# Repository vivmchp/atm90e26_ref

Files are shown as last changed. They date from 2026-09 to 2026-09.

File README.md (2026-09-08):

# ATM90E26A Evaluation Board

KiCad 10.0 design for a single-phase energy metering evaluation board based on the Microchip ATM90E26A IC.

| Front | Back |
|:-----:|:----:|
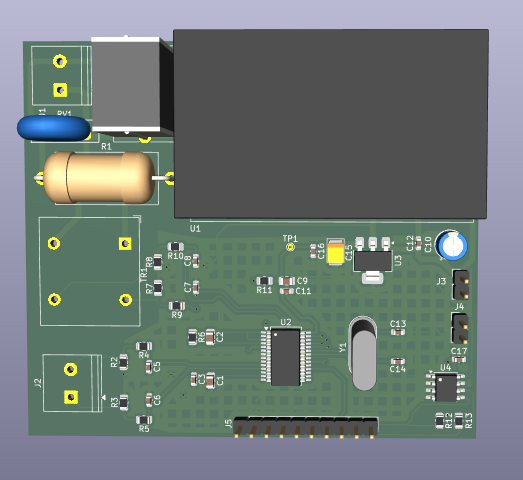
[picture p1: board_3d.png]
Board 3D Front
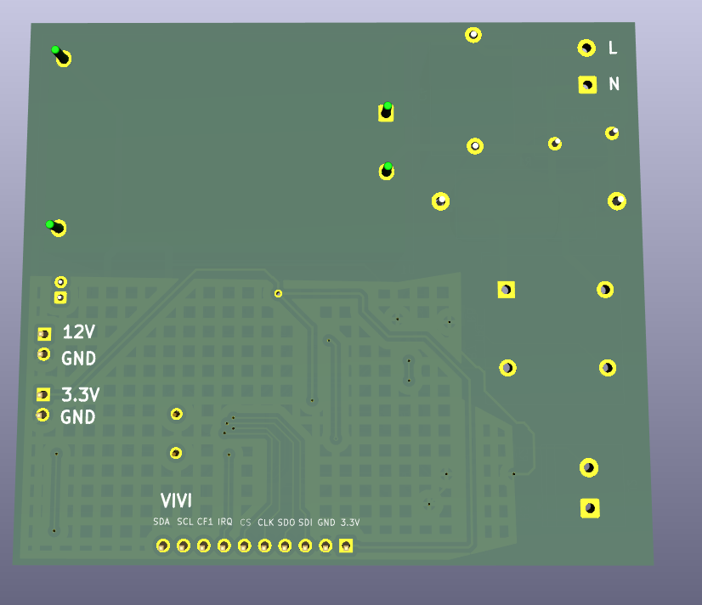
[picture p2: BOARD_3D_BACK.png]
Board 3D Back
|  |  |

## Features

- **ATM90E26A** high-precision energy metering IC (SSOP-28)
- **HLK-10M12** AC/DC power module (100-240VAC input, 12VDC/10W output)
- **ZMPT101K** voltage transformer (1000:1000) for isolated AC voltage sensing
- **MIC5209-3.3YS-TR** LDO for 3.3V power supply
- **24C02C** I2C EEPROM for calibration data storage
- **10D561** varistor for surge protection
- 10-pin header for MCU interface (SPI + I2C)
- Single-phase two-wire or three-wire configuration support

## Block Diagram

Block Diagram

## Connectors

### AC Input (J1)
| Pin | Signal | Description |
|-----|---|---|
| 1 | LINE | AC Live (100-240VAC) |
| 2 | NEUT | AC Neutral |

### Current Input (J2)
| Pin | Signal | Description |
|-----|---|---|
| 1 | I1P | Current channel positive |
| 2 | I1N | Current channel negative |

### MCU Interface (J5)
| Pin | Signal | Description |
|-----|---|---|
| 1 | +3.3V | 3.3V power output |
| 2 | GND | Ground |
| 3 | ATM_SDI | SPI data in (MOSI to ATM90E26) |
| 4 | ATM_SDO | SPI data out (MISO from ATM90E26) |
| 5 | ATM_CLK | SPI clock |
| 6 | ATM_CS | Chip select (active low) |
| 7 | ATM_IRQ | Interrupt output |
| 8 | ATM_CF1 | Energy pulse output |
| 9 | SCL | I2C clock (1K pull-up) |
| 10 | SDA | I2C data (1K pull-up) |

## PCB Specifications

| Parameter | Value |
|---|---|
| Board size | 80mm × 70mm |
| Layers | 2 (Top + Bottom copper) |
| Thickness | 1.6mm |
| Default track | 0.2mm |
| Default via | 0.6mm / 0.3mm drill |
| HV track | 1.0mm |
| HV clearance | 1.0mm |

## Bill of Materials

| Ref | Part | Value | Package |
|-----|---|---|---|
| U1 | HLK-10M12 | 12V/10W | Module |
| U2 | ATM90E26-YU | - | SSOP-28 |
| U3 | MIC5209-3.3YS-TR | 3.3V | SOT-223 |
| U4 | 24C02C | 2Kbit | SOIC-8 |
| TR1 | ZMPT101K | 1000:1000 | Through-hole |
| Y1 | Crystal | 8.192MHz | HC49-U |
| RV1 | Varistor | 10D561 | Disc |
| R1 | Resistor | 200K/3W | Axial |
| C13, C14 | Capacitor | 12pF | 0603 |

## Manufacturing Files

Gerber files for PCB fabrication are in `ATM90E26_EVAL/output/`:

| File | Description |
|---|---|
| *-F_Cu.gbr | Front copper layer |
| *-B_Cu.gbr | Back copper layer |
| *-F_Mask.gbr | Front solder mask |
| *-B_Mask.gbr | Back solder mask |
| *-F_Paste.gbr | Front solder paste |
| *-B_Paste.gbr | Back solder paste |
| *-F_Silkscreen.gbr | Front silkscreen |
| *-B_Silkscreen.gbr | Back silkscreen |
| *-Edge_Cuts.gbr | Board outline |
| *-PTH.drl | Plated through holes |
| *-NPTH.drl | Non-plated holes |

## Requirements

- KiCad 10.0 or later

## License

Reference design for evaluation purposes.

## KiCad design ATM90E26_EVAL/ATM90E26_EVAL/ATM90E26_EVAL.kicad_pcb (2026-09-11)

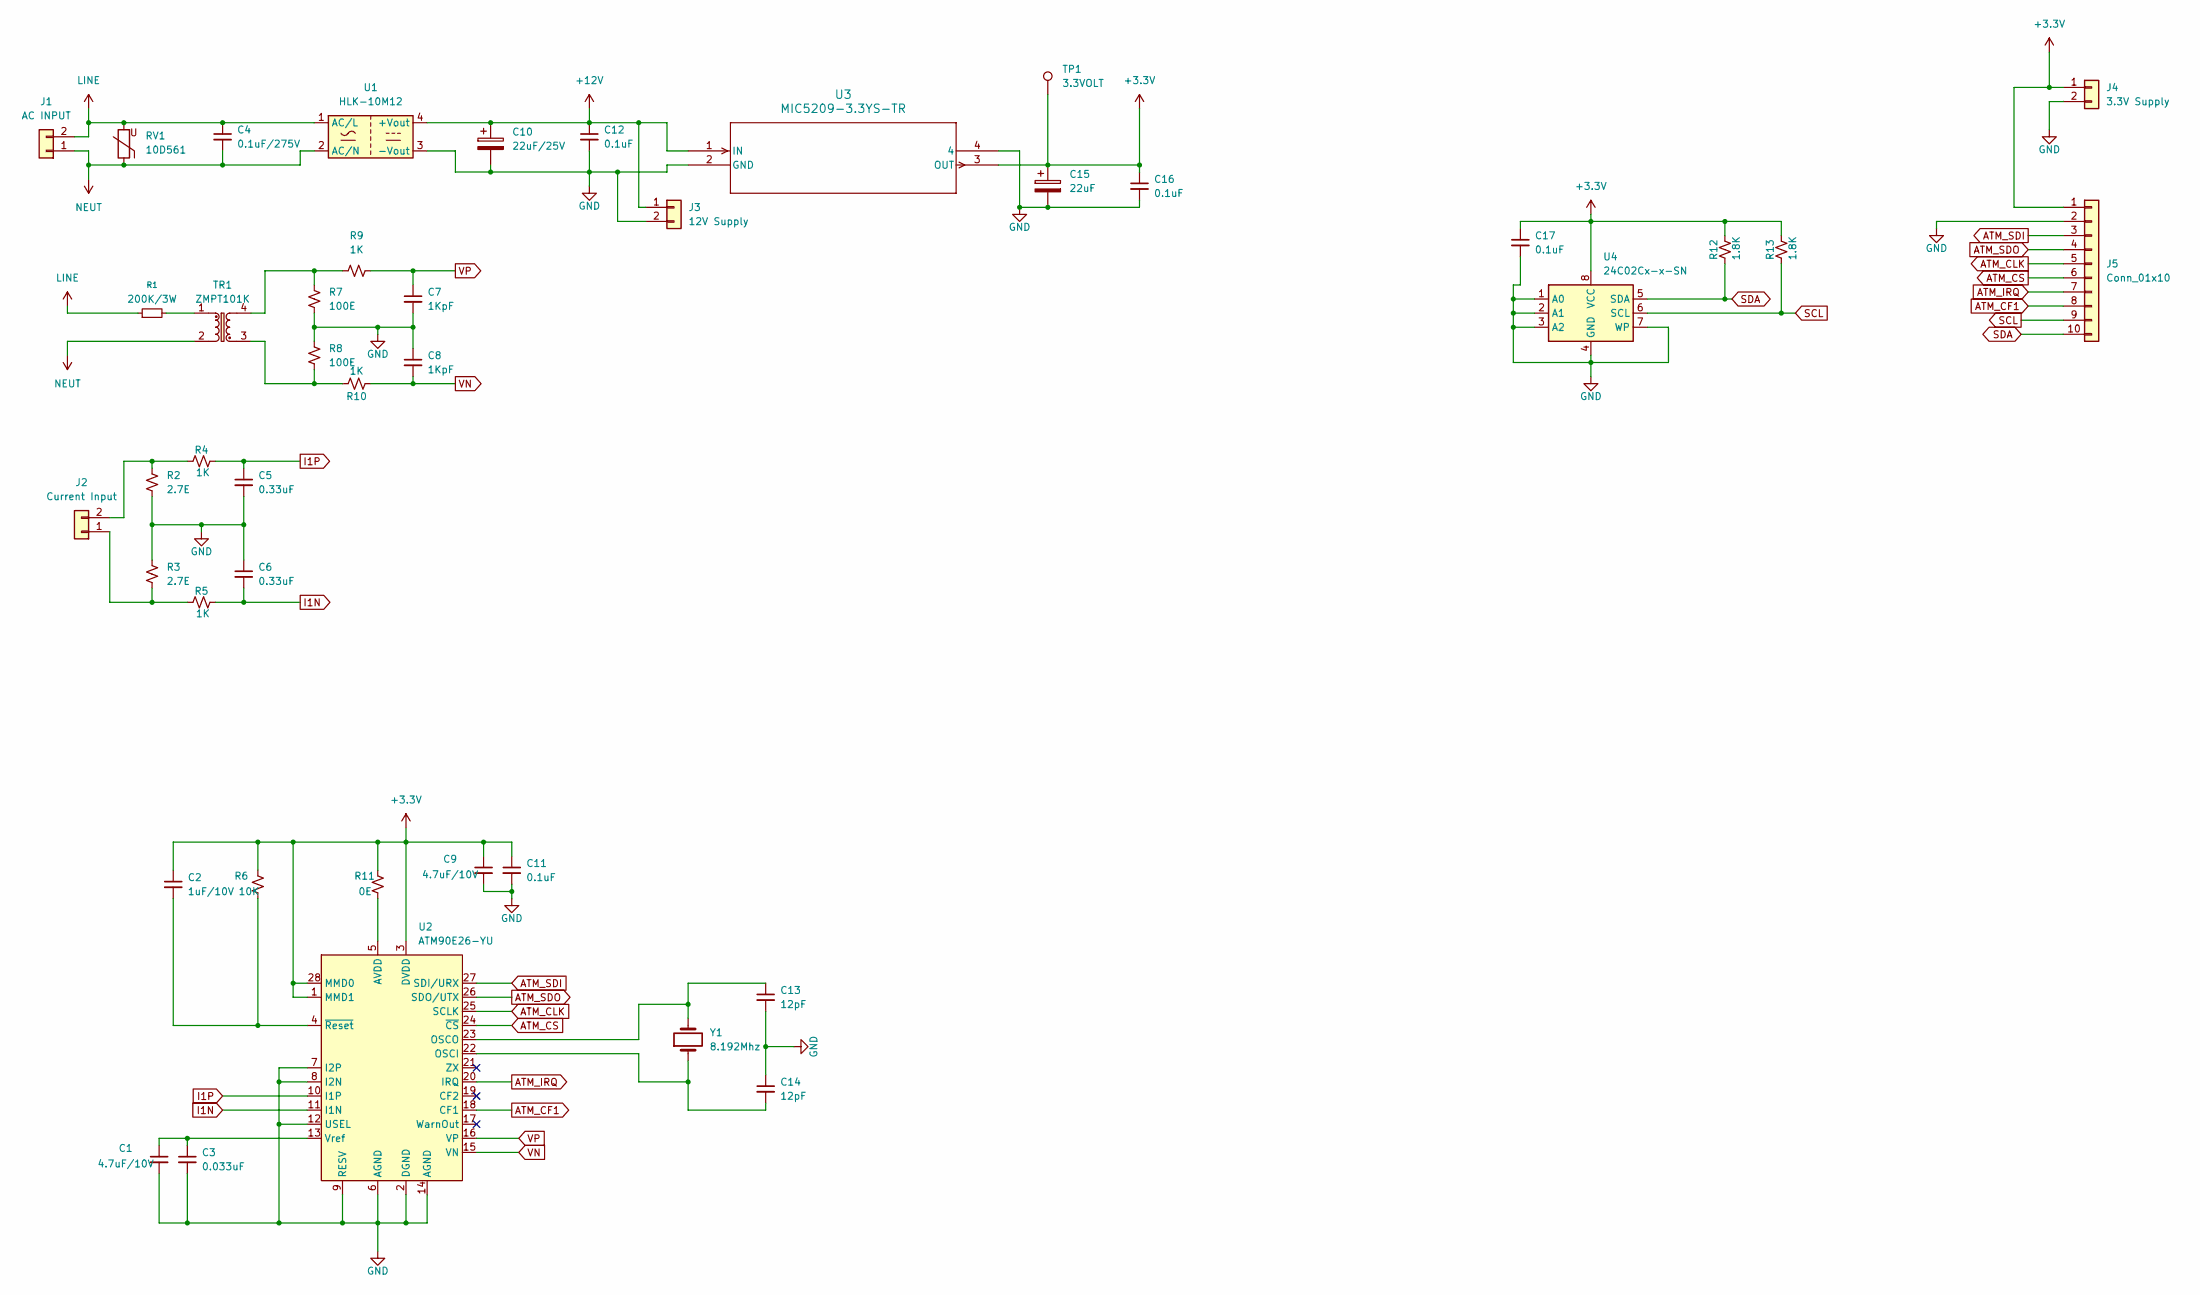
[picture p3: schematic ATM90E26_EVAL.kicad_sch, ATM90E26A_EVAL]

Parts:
C1, C9: 4.7uF/10V; C_0805_2012Metric
C2: 1uF/10V; C_0805_2012Metric
C3: 0.033uF; C_0603_1608Metric
C4: 0.1uF/275V; C_Rect_L16.5mm_W10.9mm_P15.00mm_MKT
C5, C6: 0.33uF; C_0603_1608Metric
C7, C8: 1KpF; C_0603_1608Metric
C10: 22uF/25V; CP_Radial_D5.0mm_P2.00mm
C11, C12, C16, C17: 0.1uF; C_0603_1608Metric
C13, C14: 12pF; C_0603_1608Metric
C15: 22uF; CP_EIA-3528-12_Kemet-T
J1: AC INPUT; TerminalBlock_Philmore_TB132_1x02_P5.00mm_Horizontal
J2: Current Input; TerminalBlock_Philmore_TB132_1x02_P5.00mm_Horizontal
J3: 12V Supply; PinHeader_1x02_P2.54mm_Vertical
J4: 3.3V Supply; PinHeader_1x02_P2.54mm_Vertical
J5: Conn_01x10; PinHeader_1x10_P2.54mm_Vertical
R1: 200K/3W; R_Axial_DIN0918_L18.0mm_D9.0mm_P22.86mm_Horizontal
R2, R3: 2.7E; R_0805_2012Metric
R4, R5, R9, R10: 1K; R_0805_2012Metric
R6: 10K; R_0805_2012Metric
R7, R8: 100E; R_0805_2012Metric
R11: 0E; R_0805_2012Metric
R12, R13: 1.8K; R_0805_2012Metric
RV1: 10D561; RV_Disc_D12mm_W3.9mm_P7.5mm
TP1: 3.3VOLT; TestPoint_THTPad_D1.0mm_Drill0.5mm
TR1: ZMPT101K; Transformer_Zeming_ZMPT101K
U1: HLK-10M12; Converter_ACDC_Hi-Link_HLK-10Mxx
U2: ATM90E26-YU; SSOP-28_5.3x10.2mm_P0.65mm
U3: MIC5209-3.3YS-TR; SOT-223
U4: 24C02Cx-x-SN; SOIC-8_3.9x4.9mm_P1.27mm
Y1: 8.192Mhz; Crystal_HC49-U_Vertical

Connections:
+3.3V: C2.1, C9.1, C11.1, C15.1, C16.1, C17.1, J4.1, J5.1, R6.1, R11.1, R12.1, R13.1, TP1.1 (1_1), U2.1 (MMD1), U2.3 (DVDD), U2.28 (MMD0), U3.3 (OUT), U4.8 (VCC)
+12V: C10.1, C12.1, J3.1, U1.4 (+Vout), U3.1 (IN)
ATM_CF1: J5.8, U2.18 (CF1)
ATM_CLK: J5.5, U2.25 (SCLK)
ATM_CS: J5.6, U2.24 (~CS)
ATM_IRQ: J5.7, U2.20 (IRQ)
ATM_SDI: J5.3, U2.27 (SDI/URX)
ATM_SDO: J5.4, U2.26 (SDO/UTX)
GND: C1.2, C3.2, C5.2, C6.1, C7.2, C8.1, C9.2, C10.2, C11.2, C12.2, C13.2, C14.1, C15.2, C16.2, C17.2, J3.2, J4.2, J5.2, R2.1, R3.2, R7.1, R8.2, U1.3 (-Vout), U2.2 (DGND), U2.6 (AGND), U2.7 (I2P), U2.8 (I2N), U2.9 (DGND), U2.12 (USEL), U2.14 (AGND), U3.2 (GND), U3.4, U4.1 (A0), U4.2 (A1), U4.3 (A2), U4.4 (GND), U4.7 (WP)
I1N: C6.2, R5.1, U2.11 (I1N)
I1P: C5.1, R4.1, U2.10 (I1P)
LINE: C4.1, J1.2, R1.1, RV1.2, U1.1 (AC/L)
NEUT: C4.2, J1.1, RV1.1, TR1.2, U1.2 (AC/N)
unnamed: J2.1, R3.1, R5.2
unnamed: J2.2, R2.2, R4.2
unnamed: R1.2, TR1.1
unnamed: R7.2, R9.2, TR1.4
unnamed: R8.1, R10.2, TR1.3
unnamed: R11.2, U2.5 (AVDD)
unnamed: C14.2, U2.22 (OSCI), Y1.1
unnamed: C13.1, U2.23 (OSCO), Y1.2
unnamed: C1.1, C3.1, U2.13 (Vref)
unnamed: C2.2, R6.2, U2.4 (~Reset)
SCL: J5.9, R13.2, U4.6 (SCL)
SDA: J5.10, R12.2, U4.5 (SDA)
VN: C8.2, R10.1, U2.15 (VN)
VP: C7.1, R9.1, U2.16 (VP)

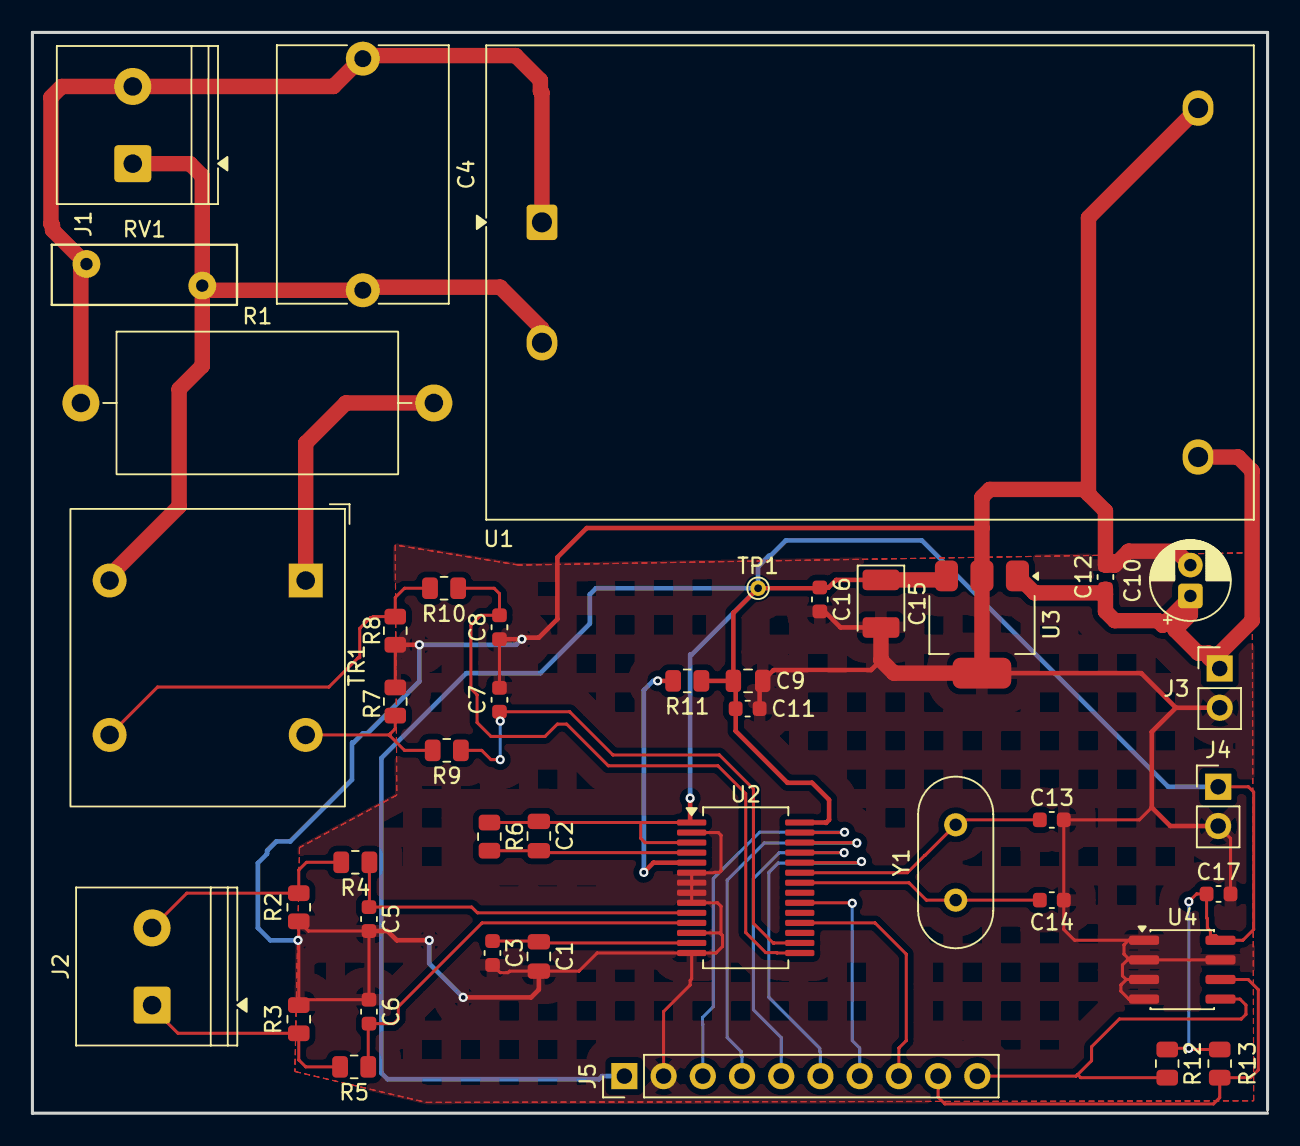
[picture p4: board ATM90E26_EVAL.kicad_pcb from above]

Board: 2 copper layers, 80.0 x 70.0 mm, 43 parts (0 on the bottom side), 27 nets.

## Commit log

2026-09-08 Initial commit: ATM90E26A energy metering evaluation board
    KiCad 10.0 project for single-phase energy metering with ATM90E26 IC,
    ZMPT101K voltage transformer, and MIC5209-3.3V LDO regulator.
    [ATM90E26_EVAL.kicad_pcb, ATM90E26_EVAL.kicad_sch, ZMPT101B_1.xlsx]
2026-09-08 Fix J5 pinout to match actual schematic net names
    ATM_SDI/SDO/CLK/CS/IRQ/CF1 for SPI interface, SCL/SDA for I2C EEPROM
2026-09-08 Update documentation with detailed design review
    - Add complete BOM with all major components
    - Document power supply chain (HLK-10M12 -> MIC5209)
    - Add voltage/current sensing circuit descriptions
    - Include block diagram in README
    - Document all connectors (J1 AC input, J2 current, J5 MCU)
    - Add PCB specifications (80x70mm, 2-layer)
    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
2026-09-08 Add 3D board render to README
2026-09-08 Add colorful SVG block diagram
    Visual block diagram showing:
    - Power supply chain (AC -> HLK-10M12 -> MIC5209)
    - Voltage and current sensing paths
    - ATM90E26 connections
    - MCU interface signals
    - Color-coded functional blocks with legend
2026-09-08 Add back side 3D view of PCB
    Shows GND pour, pin labels, and power connector markings
2026-09-08 Add gerber manufacturing files
    Output folder contains:
    - Copper layers: F_Cu, B_Cu
    - Solder mask: F_Mask, B_Mask
    - Solder paste: F_Paste, B_Paste
    - Silkscreen: F_Silkscreen, B_Silkscreen
    - Board outline: Edge_Cuts
    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
    [ATM90E26_EVAL-B_Cu.gbr, ATM90E26_EVAL-B_Mask.gbr, ATM90E26_EVAL-B_Paste.gbr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]
2026-09-08 Document gerber manufacturing files in README
2026-09-11 Optimize PCB design rules and ground plane
    - Assign LINE/NEUT nets to HighVoltage net class (1.0mm clearance)
    - Change zone fill from hatched to solid for better EMI shielding
    - Reduce zone clearance from 0.5mm to 0.35mm for denser copper fill
    - Enable corner smoothing and island removal for manufacturability
    - Add silkscreen labels for pin identification on back layer
    - Set output directory for gerber files
    [ATM90E26_EVAL.kicad_pcb]
